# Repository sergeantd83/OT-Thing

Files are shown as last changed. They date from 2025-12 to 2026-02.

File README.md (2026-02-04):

# OTthing
**a compact WiFi <-> OpenTherm (master & slave) interface**

OTthing

## Project homepage
https://www.seegel-systeme.de/2025/01/05/ot-thing-das-universelle-wifi-opentherm-interface/

## discussion
https://community.home-assistant.io/t/ot-thing-an-opentherm-wifi-gateway-with-integrated-ot-master-slave/824667

## Reporting issues
When reporting issues please supply:
* Brand & model of boiler & roomunit
* OTthing firmware version
* status JSON (http://[OTTHING-IP]/status)
* configuration JSON (http://[OTTHING-IP]/config)
* OT status JSON (http://[OTTHING-IP]/otitems)

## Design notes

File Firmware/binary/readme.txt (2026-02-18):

To install binary release:

- Hold down Boot button on OTGW32, plug in to PC, release Boot button
- Double click on flash.bat (Windows) or flash.sh (Linux)
- Press Reset on OTGW32, status LED should flash
- Configure Wi-Fi by connecting to SSID "OT Thing" pw "12345678" then visit http://4.3.2.1/

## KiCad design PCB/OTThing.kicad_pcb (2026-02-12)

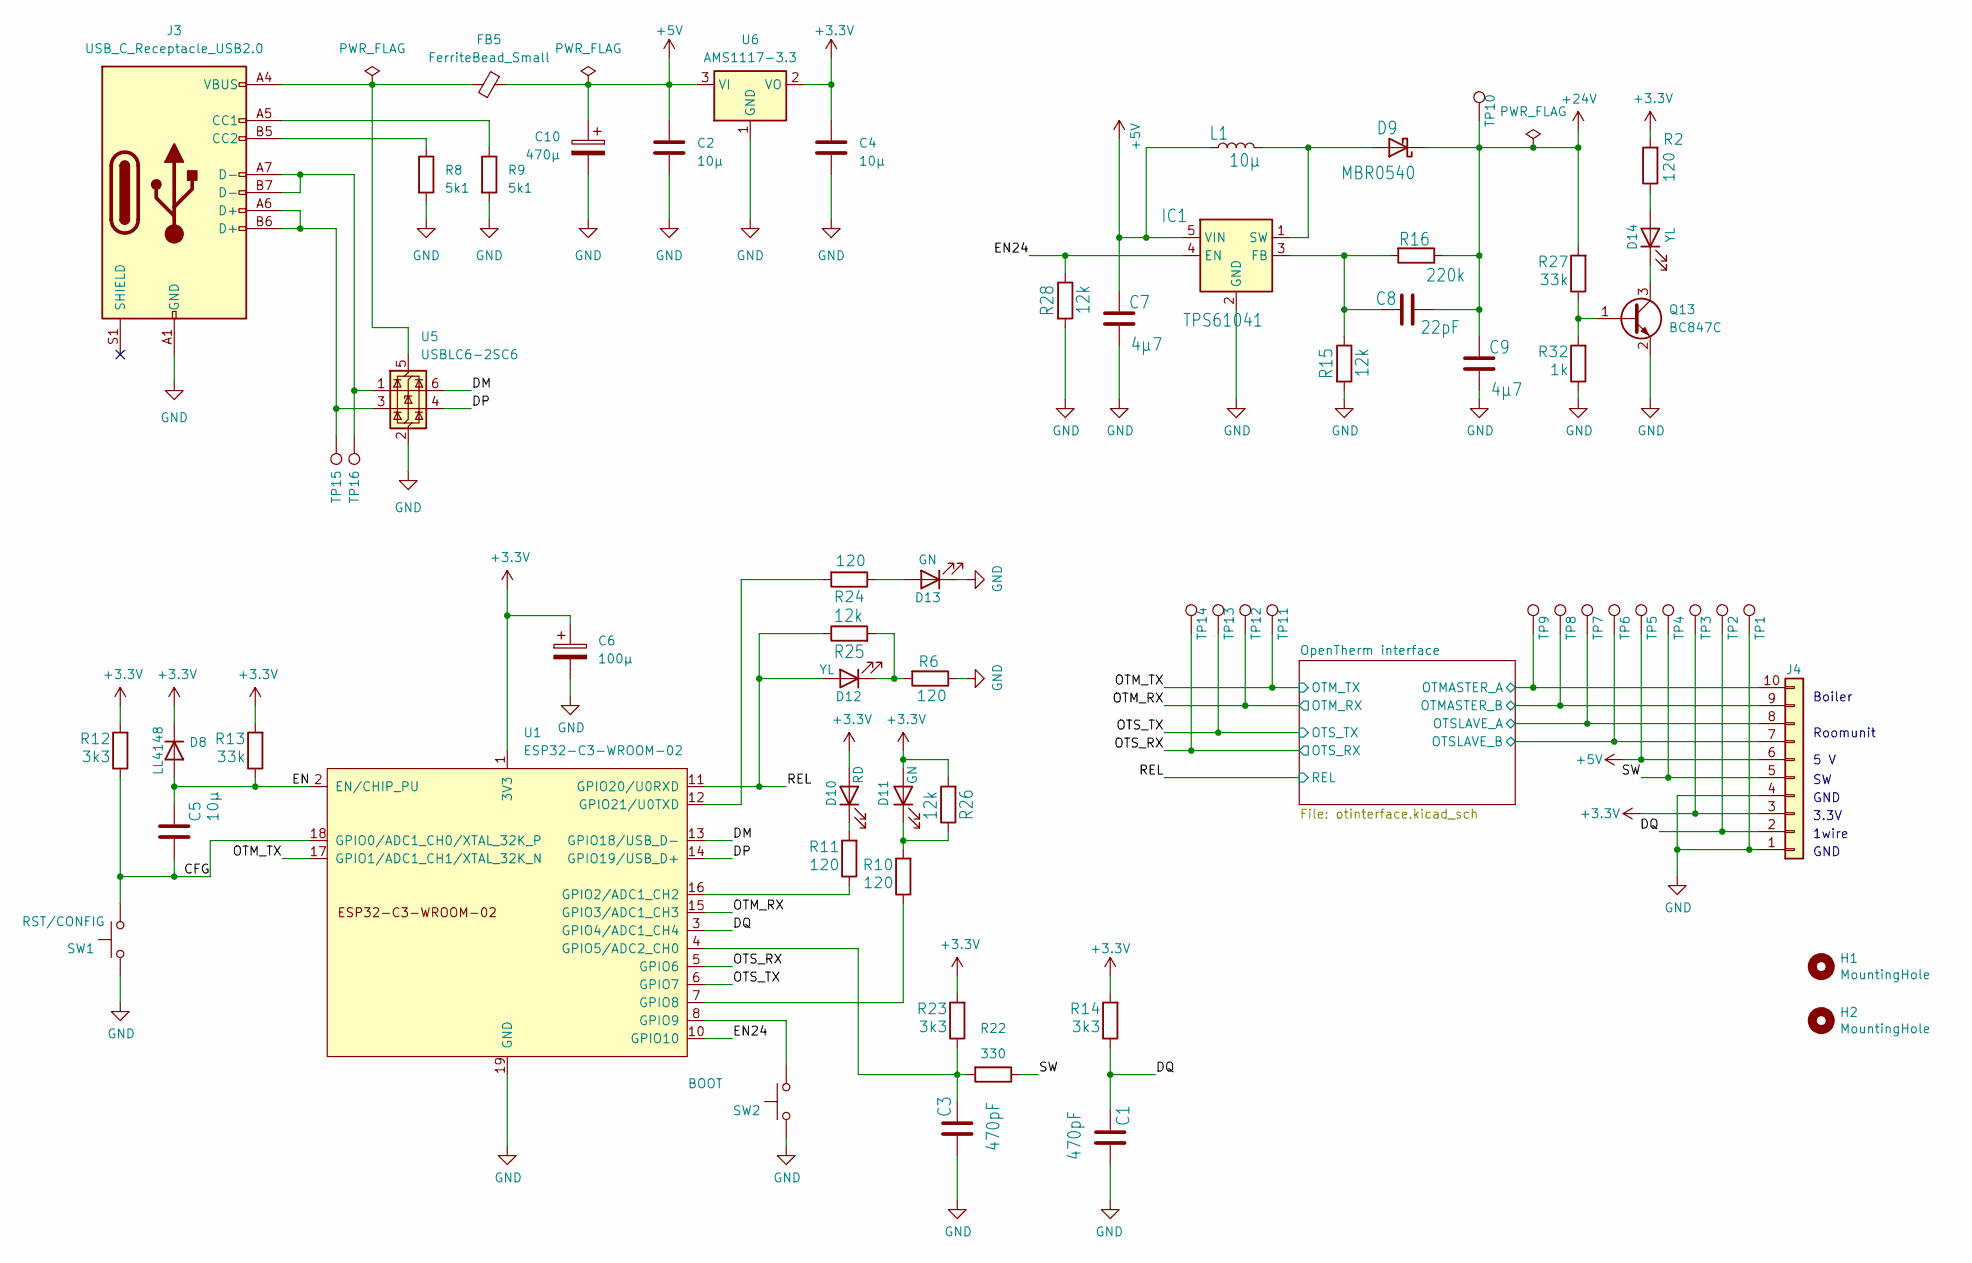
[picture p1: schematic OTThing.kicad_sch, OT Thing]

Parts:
C1, C3: 470pF; C_0805_2012Metric; LCSC C62771
C2, C4, C5: 10µ; C_0805_2012Metric; LCSC C90543
C6: 100µ; CP_Elec_6.3x5.4; LCSC C2887276
C7, C9: 4µ7; C_0805_2012Metric; LCSC C2918489
C8: 22pF; C_0805_2012Metric; LCSC C24658
C10: 470µ; CP_Elec_6.3x7.7; LCSC C87858
D8: LL4148; D_MiniMELF; LCSC C435829
D9: MBR0540; D_SOD-123; LCSC C116159
D10: RD; LED_0805_2012Metric; LCSC C2943978
D11, D13: GN; LED_0805_2012Metric; LCSC C965815
D12, D14: YL; LED_0805_2012Metric; LCSC C965816
FB5: FerriteBead_Small; L_0603_1608Metric; LCSC C1002
H1, H2: MountingHole; MountingHole_2.5mm
IC1: TPS61041; SOT-23-5; LCSC C9846
J3: USB_C_Receptacle_USB2.0; USB_C_Receptacle_HRO_TYPE-C-31-M-12; LCSC C2927038
J4: TerminalBlock_Phoenix_PT-1,5-10-3.5-H_1x10_P3.50mm_Horizont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; LCSC C5184956
L1: 10µ; L_1210_3225Metric; LCSC C98020
Q13: BC847C; SOT-23; LCSC C7420337
R2, R6, R10, R11, R24: 120; R_0805_2012Metric; LCSC C17437
R8, R9: 5k1; R_0805_2012Metric; LCSC C118848
R12, R14, R23: 3k3; R_0805_2012Metric; LCSC C26010
R13, R27: 33k; R_0805_2012Metric; LCSC C17633
R15, R25, R26, R28: 12k; R_0805_2012Metric; LCSC C17444
R16: 220k; R_0805_2012Metric; LCSC C17556
R22: 330; R_0805_2012Metric; LCSC C17630
R32: 1k; R_0805_2012Metric; LCSC C17513
SW1: RST/CONFIG; SW_Tactile_SPST_Angled_PTS645Vx83-2LFS; LCSC C2837540
SW2: BOOT; SW_SPST_CK_RS282G05A3; LCSC C2888954
TP1, TP2, TP3, TP4, TP5, TP6, TP7, TP8, TP9, TP10, TP11, TP12, TP13, TP14, TP15, TP16: TestPoint_THTPad_D1.5mm_Drill0.7mm
U1: ESP32-C3-WROOM-02; LCSC C2934560
U5: USBLC6-2SC6; SOT-23-6; LCSC C2827654
U6: AMS1117-3.3; SOT-223-3_TabPin2; LCSC C347222

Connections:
+3.3V: C4.1, C6.1, D8.1 (K), D10.2 (A), D11.2 (A), J4.3, R2.2, R12.2, R13.2, R14.2, R23.2, R26.2, TP3.1, U1.1 (3V3), U6.2 (VO); also elsewhere on the board
+5V: C2.1, C7.1, C10.1, FB5.2, IC1.5 (VIN), J4.6, L1.1, TP5.1, U6.3 (VI); also elsewhere on the board
+24V: C8.1, C9.1, D9.1 (K), R16.1, R27.2, TP10.1; also elsewhere on the board
/CFG: C5.2, R12.1, SW1.1, U1.18 (GPIO0/ADC1_CH0/XTAL_32K_P)
/DM: U1.13 (GPIO18/USB_D-), U5.6 (I/O1)
/DP: U1.14 (GPIO19/USB_D+), U5.4 (I/O2)
/DQ: C1.1, J4.2, R14.1, TP2.1, U1.3 (GPIO4/ADC1_CH4)
/EN: C5.1, D8.2 (A), R13.1, U1.2 (EN/CHIP_PU)
/EN24: IC1.4 (EN), R28.1, U1.10 (GPIO10)
/OTM_RX: TP12.1, U1.15 (GPIO3/ADC1_CH3); also elsewhere on the board
/OTM_TX: TP11.1, U1.17 (GPIO1/ADC1_CH1/XTAL_32K_N); also elsewhere on the board
/OTS_RX: TP14.1, U1.5 (GPIO6); also elsewhere on the board
/OTS_TX: TP13.1, U1.6 (GPIO7); also elsewhere on the board
/OpenTherm interface/OTMASTER_A: J4.10, TP9.1; also elsewhere on the board
/OpenTherm interface/OTMASTER_B: J4.9, TP8.1; also elsewhere on the board
/OpenTherm interface/OTSLAVE_A: J4.8, TP7.1; also elsewhere on the board
/OpenTherm interface/OTSLAVE_B: J4.7, TP6.1; also elsewhere on the board
/REL: D12.2 (A), R25.1, U1.11 (GPIO20/U0RXD); also elsewhere on the board
/SW: J4.5, R22.1, TP4.1
GND: C1.2, C2.2, C3.2, C4.2, C6.2, C7.2, C9.2, C10.2, D13.1 (K), IC1.2 (GND), J3.A1 (GND), J3.A12 (GND), J3.B1 (GND), J3.B12 (GND), J4.1, J4.4, Q13.2 (E), R6.1, R8.2, R9.2, R15.2, R28.2, R32.1, SW1.2, SW2.2, TP1.1, U1.9 (GND), U1.19 (GND), U5.2 (GND), U6.1 (GND); also elsewhere on the board
unnamed: D9.2 (A), IC1.1 (SW), L1.2
unnamed: D10.1 (K), R11.2
unnamed: D11.1 (K), R10.2, R26.1
unnamed: D12.1 (K), R6.2, R25.2
unnamed: D13.2 (A), R24.1
unnamed: D14.2 (A), R2.1
unnamed: D14.1 (K), Q13.3 (C)
unnamed: C8.2, IC1.3 (FB), R15.1, R16.2
unnamed: J3.A5 (CC1), R9.1
unnamed: J3.B5 (CC2), R8.1
unnamed: J3.A6 (D+), J3.B6 (D+), TP15.1, U5.3 (I/O2)
unnamed: J3.A7 (D-), J3.B7 (D-), TP16.1, U5.1 (I/O1)
unnamed: Q13.1 (B), R27.1, R32.2
unnamed: R11.1, U1.16 (GPIO2/ADC1_CH2)
unnamed: C3.1, R22.2, R23.1, U1.4 (GPIO5/ADC2_CH0)
unnamed: R10.1, U1.7 (GPIO8)
unnamed: SW2.1, U1.8 (GPIO9)
unnamed: R24.2, U1.12 (GPIO21/U0TXD)
unnamed: FB5.1, J3.A4 (VBUS), J3.A9 (VBUS), J3.B4 (VBUS), J3.B9 (VBUS), U5.5 (VBUS)

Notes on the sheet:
Boiler
3.3V
GND
1wire
5 V
Roomunit

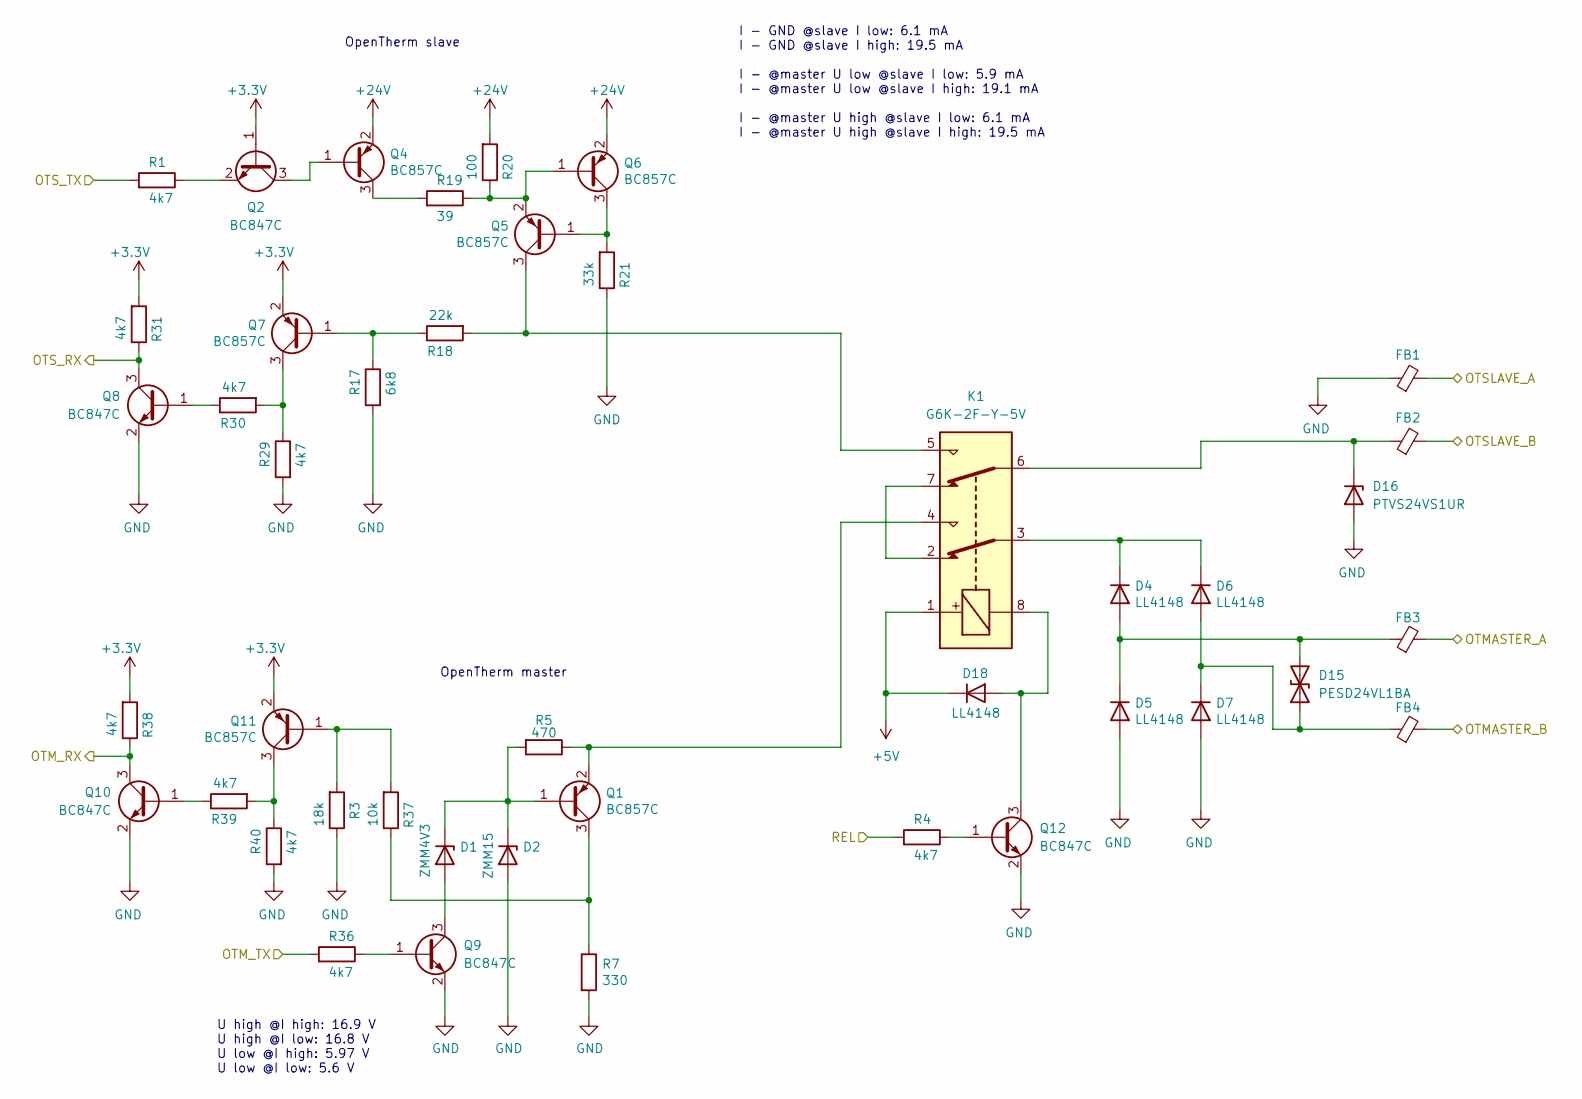
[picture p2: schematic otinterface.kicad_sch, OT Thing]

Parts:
D1: ZMM4V3; D_MiniMELF; LCSC C5345990
D2: ZMM15; D_MiniMELF; LCSC C5346000
D4, D5, D6, D7, D18: LL4148; D_MiniMELF; LCSC C435829
D15: PESD24VL1BA; D_SOD-323; LCSC C2687132
D16: PTVS24VS1UR; D_SOD-123; LCSC C5380693
FB1, FB2, FB3, FB4: L_0603_1608Metric; LCSC C1002
K1: G6K-2F-Y-5V; Relay_DPDT_Omron_G6K-2F-Y; LCSC C2982926
Q1, Q4, Q5, Q6, Q7, Q11: BC857C; SOT-23; LCSC C5204725
Q2, Q8, Q9, Q10, Q12: BC847C; SOT-23; LCSC C7420337
R1, R4, R29, R30, R31, R36, R38, R39, R40: 4k7; R_0805_2012Metric; LCSC C17673
R3: 18k; R_0805_2012Metric; LCSC C17506
R5: 470; R_0805_2012Metric; LCSC C17710
R7: 330; R_0805_2012Metric; LCSC C17630
R17: 6k8; R_0805_2012Metric; LCSC C17772
R18: 22k; R_0805_2012Metric; LCSC C17560
R19: 39; R_0805_2012Metric; LCSC C137534
R20: 100; R_0805_2012Metric; LCSC C17408
R21: 33k; R_0805_2012Metric; LCSC C17633
R37: 10k; R_0805_2012Metric; LCSC C17414

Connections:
+3.3V: Q2.1 (B), Q7.2 (E), Q11.2 (E), R31.2, R38.2; also elsewhere on the board
+5V: D18.1 (K), K1.1; also elsewhere on the board
+24V: Q4.2 (E), Q6.2 (E), R20.2; also elsewhere on the board
/OTM_RX: Q10.3 (C), R38.1; also elsewhere on the board
/OTM_TX: R36.2; also elsewhere on the board
/OTS_RX: Q8.3 (C), R31.1; also elsewhere on the board
/OTS_TX: R1.2; also elsewhere on the board
/OpenTherm interface/OTMASTER_A: FB3.2; also elsewhere on the board
/OpenTherm interface/OTMASTER_B: FB4.2; also elsewhere on the board
/OpenTherm interface/OTSLAVE_A: FB1.2; also elsewhere on the board
/OpenTherm interface/OTSLAVE_B: FB2.2; also elsewhere on the board
/REL: R4.2; also elsewhere on the board
GND: D2.2 (A), D5.2 (A), D7.2 (A), D16.2 (A), FB1.1, Q8.2 (E), Q9.2 (E), Q10.2 (E), Q12.2 (E), R3.1, R7.2, R17.2, R21.1, R29.2, R40.2; also elsewhere on the board
unnamed: D1.2 (A), Q9.3 (C)
unnamed: D1.1 (K), D2.1 (K), Q1.1 (B), R5.2
unnamed: D4.1 (K), D6.1 (K), K1.3
unnamed: D6.2 (A), D7.1 (K), D15.1 (A1), FB4.1
unnamed: D4.2 (A), D5.1 (K), D15.2 (A2), FB3.1
unnamed: D16.1 (K), FB2.1, K1.6
unnamed: D18.2 (A), K1.8, Q12.3 (C)
unnamed: K1.2, K1.7
unnamed: Q1.3 (C), R7.1, R37.1
unnamed: K1.4, Q1.2 (E), R5.1
unnamed: Q2.3 (C), Q4.1 (B)
unnamed: Q2.2 (E), R1.1
unnamed: Q4.3 (C), R19.2
unnamed: Q5.1 (B), Q6.3 (C), R21.2
unnamed: K1.5, Q5.3 (C), R18.2
unnamed: Q5.2 (E), Q6.1 (B), R19.1, R20.1
unnamed: Q7.1 (B), R17.1, R18.1
unnamed: Q7.3 (C), R29.1, R30.2
unnamed: Q8.1 (B), R30.1
unnamed: Q9.1 (B), R36.1
unnamed: Q10.1 (B), R39.1
unnamed: Q11.1 (B), R3.2, R37.2
unnamed: Q11.3 (C), R39.2, R40.1
unnamed: Q12.1 (B), R4.1

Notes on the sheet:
U high @I high: 16.9 V U high @I low: 16.8 V U low @I high: 5.97 V U low @I low: 5.6 V
I - GND @slave I low: 6.1 mA I - GND @slave I high: 19.5 mA I - @master U low @slave I low: 5.9 mA I - @master U low @slave I high: 19.1 mA I - @master U high @slave I low: 6.1 mA I - @master U high @slave I high: 19.5 mA
OpenTherm slave
OpenTherm master

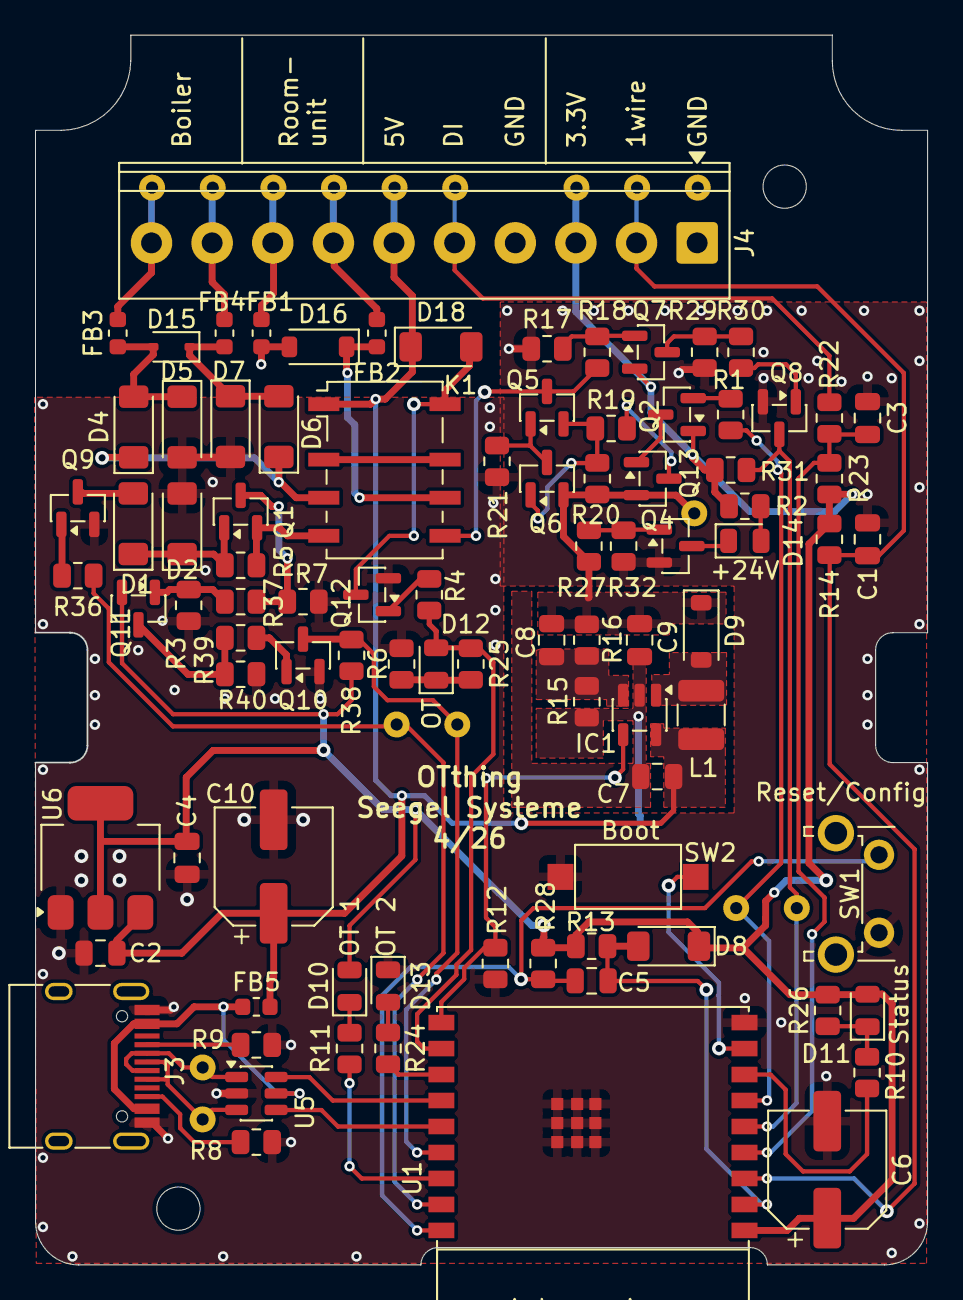
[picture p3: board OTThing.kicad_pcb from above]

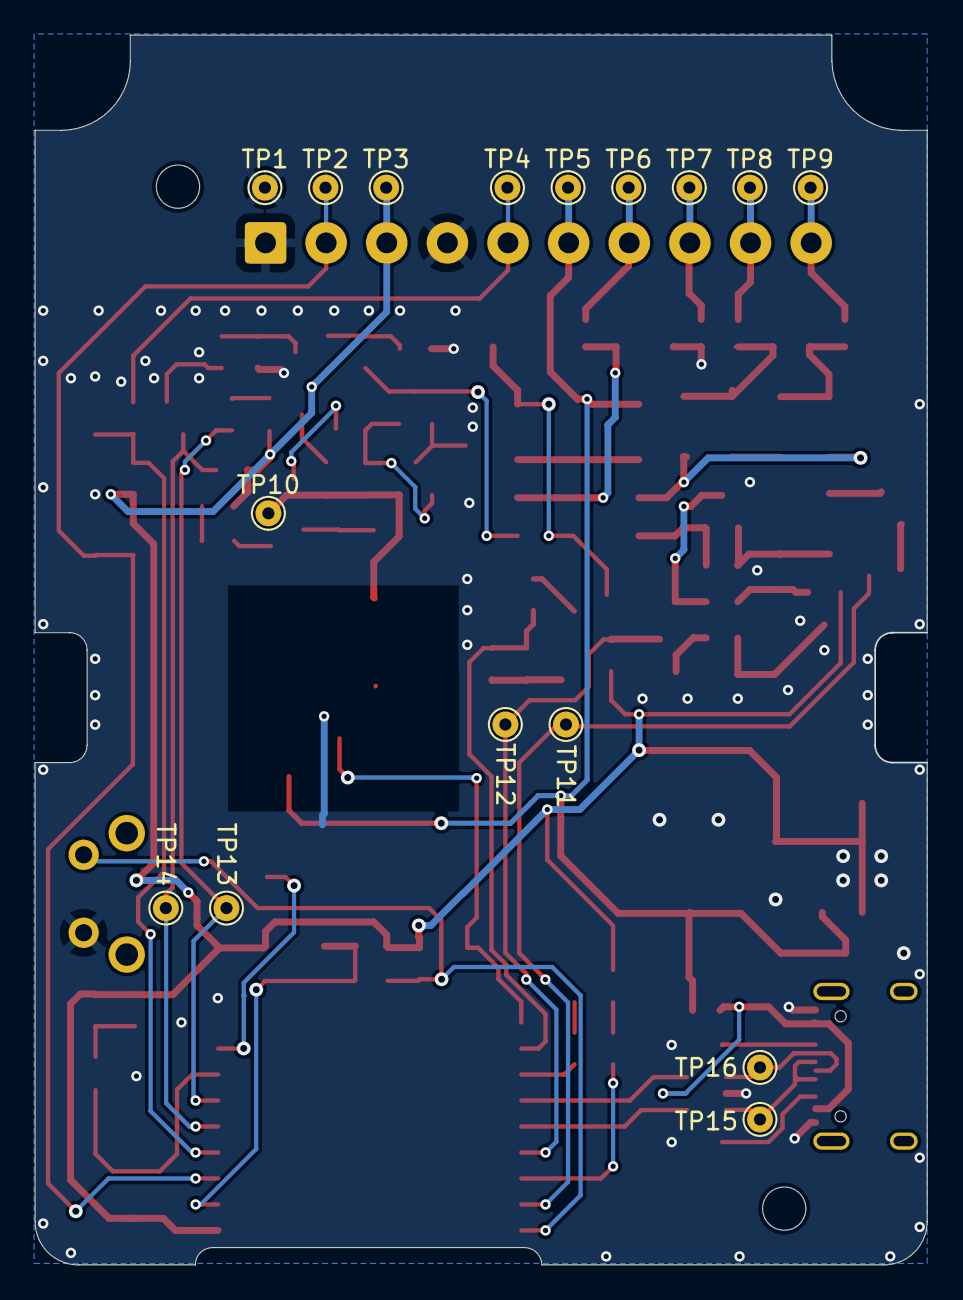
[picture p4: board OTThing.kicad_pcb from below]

Board: 2 copper layers, 51.5 x 71.0 mm, 108 parts (16 on the bottom side), 63 nets.

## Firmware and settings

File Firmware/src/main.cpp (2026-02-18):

#include <Arduino.h>
#include <SPI.h>
#include <WiFi.h>
#include <ESPmDNS.h>
#include <Ticker.h>
#include "hwdef.h"
#include "portal.h"
#include "otcontrol.h"
#include "mqtt.h"
#include "devstatus.h"
#include "devconfig.h"
#include "command.h"
#include "sensors.h"
#include "HADiscLocal.h"
#include <esp_wifi.h>
#include "time.h"
#include "main.h"
#include "esp_task_wdt.h"

#ifdef DEBUG
    #include <ArduinoOTA.h>
#endif

#ifdef NODO
#include <EthernetESP32.h>
SPIClass SPI1(FSPI);
W5500Driver driver(GPIO_SPI_CS, GPIO_SPI_INT, GPIO_SPI_RST);
char buffer[64]; 
byte ethMac[6];
#endif

Ticker statusLedTicker;
volatile uint16_t statusLedData = 0x8000;
bool configMode = false;


// Variables for dynamic network management
unsigned long lastNetworkCheck = 0;
const unsigned long netCheckInterval = 5000; // Check physical link every 5 seconds

void statusLedLoop() {
    static uint16_t mask = 0x8000;

    setLedStatus((statusLedData & mask) != 0);
    mask >>= 1;
    if (!mask)
        mask = 0x8000;
}

void wifiEvent(WiFiEvent_t event) {
#ifdef NODO
    if (configMode) return;
#endif
    switch (event) {
    case ARDUINO_EVENT_WIFI_STA_GOT_IP: {
        String hn = devconfig.getHostname();
        WiFi.setHostname(hn.c_str());
        MDNS.begin(hn.c_str());
        MDNS.addService("http", "tcp", 80);
        break;
    }

    case ARDUINO_EVENT_WIFI_STA_DISCONNECTED:
        // Only trigger reconnect if we aren't currently using Wired Ethernet
        if (!WIRED_ETHERNET_PRESENT) {
            devstatus.numWifiDiscon++;
            WiFi.reconnect();
        }
        break;

    default:
        break;
    }
}



#ifdef NODO
QueueHandle_t button_press_queue;
void IRAM_ATTR nodo_boot_button_interrupt(void *arg) {
  if ( gpio_get_level((gpio_num_t)GPIO_BOOT_BUTTON) == 0 ){
    int64_t t = esp_timer_get_time();
    xQueueSendFromISR(button_press_queue, &t, NULL);
  }
}
const int number_of_pages = 5;
int64_t last_c = 0;
int pageno = 0;

Adafruit_SSD1306 oled_display(SCREEN_WIDTH, SCREEN_HEIGHT, &Wire, -1);

void displayNetworkStatus(unsigned long now) {
  if (!OLED_PRESENT)
      return; // Skip if no display detected

  static unsigned long on_time = 0;
  static int last_pageno_state = 0;

  int64_t c = 0;
  while (xQueueReceive(button_press_queue, &c, 0)) {
    // Debounce check
    if ( (c - last_c ) < 300000 ){
      last_c = c;
      continue;
    }
    last_c = c;
    
    // Cycle pages or turn on if it was off
    if (pageno == 0) {
        pageno = 1;
    } else {
        pageno++;
        if (pageno >= number_of_pages) pageno = 1;
    }
    on_time = now; // Reset timer on manual interaction
  } 

  // --- AUTOMATIC WAKE LOGIC ---
  // If pageno was just set to 1 (by manageNetwork OR button) and it was previously 0
  if (pageno > 0 && last_pageno_state == 0) {
      oled_display.ssd1306_command(SSD1306_DISPLAYON);
      oled_display.setTextSize(1);
      oled_display.setTextColor(SSD1306_WHITE);
      if (on_time == 0) on_time = now; // Only set if not already set by button
  }

  // --- TIMEOUT LOGIC ---
  if ( pageno > 0 && (now - on_time) > 30000 ) {
      oled_display.ssd1306_command(SSD1306_DISPLAYOFF);
      pageno = 0;
      on_time = 0;
  }
  
  last_pageno_state = pageno;

  if (pageno) { // display on, needs updating
    oled_display.clearDisplay();
    oled_display.setCursor(0, 0);
    
    if (pageno==1) {
      if (configMode) { // in config mode
        // Using snprintf to format the string into the buffer
        snprintf(buffer, sizeof(buffer), "SSID: %s", WiFi.softAPSSID().c_str());
        oled_display.println(buffer);
        
        oled_display.setCursor(0, 10);
        snprintf(buffer, sizeof(buffer), "PW: 12345678");
        oled_display.println(buffer);

        oled_display.setCursor(0, 20);
        snprintf(buffer, sizeof(buffer), "http://%s/", WiFi.softAPIP().toString().c_str());
        oled_display.println(buffer);
      } else { // not config mode
        if (WIRED_ETHERNET_PRESENT) { // wired
            oled_display.println(F("Wired Network"));
            
            oled_display.setCursor(0, 10);
            snprintf(buffer, sizeof(buffer), "IP: %s", Ethernet.localIP().toString().c_str());
            oled_display.println(buffer);
        } else { // wifi
          snprintf(buffer, sizeof(buffer), "WiFi: %s", WiFi.SSID().c_str());
          oled_display.println(buffer);

          oled_display.setCursor(0, 10);
          if (WiFi.isConnected()) {
              snprintf(buffer, sizeof(buffer), "IP: %s", WiFi.localIP().toString().c_str());
              oled_display.println(buffer);
          } else {
              oled_display.println(F("Connecting..."));
          }
        }
        oled_display.setCursor(0,30);
        oled_display.println("Press Boot for more");
      } // config mode
    } else if ( pageno > 1 ) { 
      if (millis() > 5000) { 
          devstatus.lock(); 
          JsonDocument doc;
          devstatus.buildDoc(doc);

      if ( pageno == 2 || pageno == 3 ){
        snprintf(buffer, sizeof(buffer), "Heating circuit %d", pageno-1);
        oled_display.println(buffer);
        oled_display.println("");
        JsonArray array = doc["heatercircuit"].as<JsonArray>();
        if ( !array.isNull() && array.size() > (pageno-2) ){
          auto obj = array[pageno-2].as<JsonObject>();
          if ( !obj["roomsetpoint"].isNull() ){
            float rsp = obj["roomsetpoint"];
            snprintf(buffer, sizeof(buffer), "Room setpoint: %.1f", rsp);
            oled_display.println(buffer);
          }
          if ( !obj["roomtemp"].isNull() ){
            float rsp = obj["roomtemp"];
            snprintf(buffer, sizeof(buffer), "Room temp:     %.1f", rsp);
            oled_display.println(buffer);
          }
        } else {
          oled_display.println("Not Found.");
        }
      } else if (pageno == 4 ){
        snprintf(buffer, sizeof(buffer), "Status");
        oled_display.println(buffer);
        oled_display.println("");

        String str = doc["fw_version"];
        snprintf(buffer, sizeof(buffer), "FW version: %s", str.c_str());
        oled_display.println(buffer);
        unsigned ut = doc["runtime"];
        snprintf(buffer, sizeof(buffer), "Runtime:    %u s", ut);
        oled_display.println(buffer);
        if ( !doc["mqtt"].isNull() ){
          snprintf(buffer, sizeof(buffer), "MQTT:       %s", doc["mqtt"]["connected"] == false? "disconnected":"connected");
          oled_display.println(buffer);
          if ( doc["mqtt"]["basetopic"].isNull() ){
            snprintf(buffer, sizeof(buffer), "MQTT topic: n/a");
          } else {
            String str = doc["mqtt"]["basetopic"];
            snprintf(buffer, sizeof(buffer), "MQTT topic: %s", str.c_str());
          }
          oled_display.println(buffer);
        }

      }
      devstatus.unlock();
      } else {
          oled_display.println(F("Loading data..."));
      } 
    }
    // --- Memory Status ---
    // oled_display.setCursor(0, 20);
    // %u is for unsigned int, %lu is for long unsigned (safer for 32-bit heap values)
    // snprintf(buffer, sizeof(buffer), "%lu bytes free", (unsigned long)ESP.getFreeHeap());
    // oled_display.println(buffer);
    
    oled_display.display();
  }
}

// Helper to switch interfaces based on physical link
void manageNetwork() {
    unsigned long now = millis();
    if (now - lastNetworkCheck < netCheckInterval) return;
    lastNetworkCheck = now;

    bool hasLink = (Ethernet.linkStatus() == LinkON);

    // If Ethernet cable just plugged in, but we are currently on WiFi
    if (hasLink && !WIRED_ETHERNET_PRESENT) {
        Serial.println("Ethernet link detected. Switching to Wired...");
        if (!pageno) pageno=1; // wake display
        if (Ethernet.begin(ethMac, 2000)) { 
            WIRED_ETHERNET_PRESENT = true;
            WiFi.disconnect(); // Turn off WiFi to avoid routing conflicts
            Serial.print("Wired IP: ");
            Serial.println(Ethernet.localIP());
            
            String hn = devconfig.getHostname();
            MDNS.begin(hn.c_str());
        }
    } 
    // If Ethernet cable unplugged, but we were using Wired
    else if (!hasLink && WIRED_ETHERNET_PRESENT) {
        if (!pageno) pageno=1; // wake display
        Serial.println("Ethernet link lost. Switching to WiFi...");
        WIRED_ETHERNET_PRESENT = false;
        WiFi.begin(); 
    }
}
#endif // NODO

void setup() {
    Serial.begin();
    Serial.setTxTimeoutMs(100);
    pinMode(GPIO_STATUS_LED, OUTPUT);
    pinMode(GPIO_CONFIG_BUTTON, INPUT);
    
    setLedStatus(false);
#ifdef NODO  // Initialize I2C display and wired ethernet
    const unsigned char flame_bitmap[] PROGMEM = {
        0x01, 0x00, 0x01, 0x00, 0x03, 0x00, 0x03, 0x80, 0x07, 0x80, 0x0f, 0xc0, 0x1f, 0xe0, 0x3f, 0xf0, 
        0x3f, 0xf0, 0x7f, 0xf8, 0x77, 0xf8, 0x73, 0xf8, 0xff, 0xf8, 0xff, 0xf8, 0x3f, 0xf0, 0x1f, 0xe0
    };
    Wire.begin(GPIO_I2C_SDA, GPIO_I2C_SCL);  // SDA=21, SCL=22 (default ESP32 pins)

    // Initialize OLED
    Wire.beginTransmission(0x3C);
    if (Wire.endTransmission() == 0) { // device responded
    if (oled_display.begin(SSD1306_SWITCHCAPVCC, 0x3C)) {
      // Clear buffer
      oled_display.clearDisplay();

      // Set text properties
      oled_display.setTextSize(1);             // Text size multiplier
      oled_display.setTextColor(SSD1306_WHITE);
      oled_display.setCursor(0, 0);          // Position on screen

      // Print message
      oled_display.println("Nodo OTGW32");
      oled_display.setCursor(0, 20);          // Position on screen
      oled_display.println("Press Boot for more");
      oled_display.setCursor(0, 30);          // Position on screen
      oled_display.println("Hold Reset for config");

      // pretty flame
      oled_display.drawBitmap(56, 44, flame_bitmap, 16, 16, WHITE);
      // Push to display
      oled_display.display();
      OLED_PRESENT = true;
      pageno = 1;
    }
  }
  button_press_queue = xQueueCreate(10, sizeof(int64_t));
  gpio_set_direction((gpio_num_t)GPIO_BOOT_BUTTON, GPIO_MODE_INPUT);
  gpio_install_isr_service(ESP_INTR_FLAG_IRAM);
  gpio_set_intr_type((gpio_num_t)GPIO_BOOT_BUTTON, GPIO_INTR_NEGEDGE);
  gpio_intr_enable((gpio_num_t)GPIO_BOOT_BUTTON);
  gpio_isr_handler_add((gpio_num_t)GPIO_BOOT_BUTTON, nodo_boot_button_interrupt,
                       NULL);
  // Initialize Ethernet
  SPI1.begin(GPIO_SPI_SCK, GPIO_SPI_MISO, GPIO_SPI_MOSI);
  driver.setSPI(SPI1);
  driver.setSpiFreq(10);
  driver.setPhyAddress(0);
  Ethernet.init(driver);
  {
    // Get ESP32 MAC
    uint64_t mac64 = ESP.getEfuseMac();
    for (int i = 0; i < 6; i++) {
      ethMac[5 - i] = (mac64 >> (8 * i)) & 0xFF;
    }
    // Mark as locally administered (set bit 1 of first byte)
    ethMac[0] |= 0x02;

    Serial.printf("Derived W5500 MAC: %02X:%02X:%02X:%02X:%02X:%02X\n",
                  ethMac[0], ethMac[1], ethMac[2], ethMac[3], ethMac[4],
                  ethMac[5]);

    // Fast check at boot
    if (Ethernet.begin(ethMac, 1000)) {
      if (Ethernet.linkStatus() == LinkON) {
        WIRED_ETHERNET_PRESENT = true;
      }
    }
  }
#endif
  otcontrol.begin();

  statusLedTicker.attach(0.2, statusLedLoop);

    configMode = digitalRead(GPIO_CONFIG_BUTTON) == 0;
    if (configMode)
        statusLedData = 0xA000;
#ifdef NODO
    if (configMode) {
        WiFi.mode(WIFI_OFF); 
        delay(50);
        WiFi.mode(WIFI_AP); 
    }
#else
    Serial.begin();
    Serial.setTxTimeoutMs(100);
#endif
#ifdef NODO
    if (!configMode) {
#endif
        WiFi.onEvent(wifiEvent);
        WiFi.setSleep(false);
        WiFi.begin();
        AddressableSensor::begin();
        OneWireNode::begin();
        BLESensor::begin();
        haDisc.begin();
        mqtt.begin();
#ifdef NODO
    } 
#endif

    // This is now outside the block, fixing the crash in Config Mode
    devconfig.begin(); 
    configTime(devconfig.getTimezone(), 3600, PSTR("pool.ntp.org"));
#ifdef NODO
    devstatus.lock();
    delay(50); // Hold it long enough for the RTOS to register the allocation
    devstatus.unlock();
#endif
    portal.begin(configMode);

#ifdef NODO
    delay(500);
    if (!configMode)
#endif
        command.begin();
#ifdef NODO
    if (!configMode) { // Only enable the watchdog in Normal Mode
#endif
        esp_task_wdt_config_t wdt_config = {
#ifdef NODO
            .timeout_ms = 10000,
            .idle_core_mask = (1 << 0) | (1 << 1), // check both cores
#else
            .timeout_ms = 6000,
            .idle_core_mask = (1 << 0), // check both cores
#endif
            .trigger_panic = true
        };
        esp_task_wdt_init(&wdt_config);
        esp_task_wdt_add(NULL);
#ifdef NODO
    }
#endif
#ifdef DEBUG
    ArduinoOTA.begin();
#endif
}

void loop() {
    unsigned long now = millis();
#ifdef NODO
    yield(); // keep WDT happy
    if (!configMode) {
#endif
    static unsigned long btnDown = 0;
    if (digitalRead(GPIO_CONFIG_BUTTON) == 0) {
        if ((now - btnDown) > 10000) {
            statusLedTicker.detach();
            setLedStatus(true);
            devconfig.remove();
            WiFi.persistent(true);
            WiFi.disconnect(true, true);
            while (digitalRead(GPIO_CONFIG_BUTTON) == 0) {
                esp_task_wdt_reset();
                yield();
            }
            ESP.restart();
        }
        esp_task_wdt_reset();
    }
    else
        btnDown = now;
#ifdef NODO
    }
#endif 

#ifdef DEBUG
    ArduinoOTA.handle();
#endif
    
#ifdef NODO
    // Check for physical link status and swap if needed
    if (!configMode) 
        manageNetwork();
    else
        delay(1); // keep WDT happy

    static unsigned long lastDisplayUpdate = 0;
    if (now - lastDisplayUpdate > 1000 || uxQueueMessagesWaiting(button_press_queue)) { 
        displayNetworkStatus(now); 
        lastDisplayUpdate = now;
    }

    if (WIRED_ETHERNET_PRESENT) 
        Ethernet.maintain(); /* keep DHCP lease etc */
#endif 

    esp_task_wdt_reset();
    portal.loop();
    mqtt.loop();
    otcontrol.loop();
    Sensor::loopAll();
    devconfig.loop();
    OneWireNode::loop();
}

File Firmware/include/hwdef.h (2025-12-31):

#pragma once
#ifdef NODO
/* probably should be here for all versions */
#include <WiFi.h>
// for OLED display
#include <Wire.h>
#include <Adafruit_GFX.h>
#include <Adafruit_SSD1306.h>
// for W5500 wi-fi
#include <SPI.h>
#include <Ethernet.h>
extern bool WIRED_ETHERNET_PRESENT; 
/* pin defs for Nodo OTGW32 PCB */
#define GPIO_BOOT_BUTTON 0
#define GPIO_CONFIG_BUTTON 9
#define GPIO_STATUS_LED 8
#define GPIO_OTRED_LED 2
#define GPIO_OTGREEN_LED 48
#define GPIO_BYPASS_RELAY 47 /* not connected on Nodo but need for compilation */
#define GPIO_STEPUP_ENABLE 10
#define GPIO_1WIRE_DIO 4
#define GPIO_OTSLAVE_IN 6
#define GPIO_OTSLAVE_OUT 7
#define GPIO_OTMASTER_IN 21
#define GPIO_OTMASTER_OUT 1
/* for I2C OLED display */
#define GPIO_I2C_SCL 17
#define GPIO_I2C_SDA 18
#define GPIO_SPI_CS 14
/* for SPI W5500 Ethernet */
#define GPIO_SPI_MISO 13
#define GPIO_SPI_MOSI 11
#define GPIO_SPI_SCK 12
#define GPIO_SPI_INT 15
#define GPIO_SPI_RST 16
// OLED display width and height
#define SCREEN_WIDTH 128
#define SCREEN_HEIGHT 64
#define LED_BRIGHTNESS 5 // 0-255 
#else
#define GPIO_CONFIG_BUTTON 0
#define GPIO_STATUS_LED 8
#define GPIO_OTRED_LED 2
#define GPIO_OTGREEN_LED 21
#define GPIO_BYPASS_RELAY 20
#define GPIO_STEPUP_ENABLE 10
#define GPIO_1WIRE_DIO 4
#define GPIO_OTSLAVE_IN 6
#define GPIO_OTSLAVE_OUT 7
#define GPIO_OTMASTER_IN 3
#define GPIO_OTMASTER_OUT 1
#endif

inline void setLedOTRed(const bool on) {
#ifdef NODO
    static int init = 0;
    if ( !init ) {
      ledcAttachChannel(GPIO_OTRED_LED, 5000, 8, 2); 
      ledcOutputInvert(GPIO_OTRED_LED, true);
      init = 1;
    }
    if (!on) {
      ledcWrite(GPIO_OTRED_LED, 0);
    } else {
      ledcWrite(GPIO_OTRED_LED, LED_BRIGHTNESS); // dim
    }
#else
    digitalWrite(GPIO_OTRED_LED, !on);
#endif
}

inline void setLedOTGreen(const bool on) {
#ifdef NODO
    static int init = 0;
    if ( !init ) {
      ledcAttachChannel(GPIO_OTGREEN_LED, 5000, 8, 1); 
      ledcOutputInvert(GPIO_OTGREEN_LED, false);
      init = 1;
    }
    if (!on) {
      ledcWrite(GPIO_OTGREEN_LED, 0);
    } else {
      ledcWrite(GPIO_OTGREEN_LED, LED_BRIGHTNESS); // dim
    }
#else
    digitalWrite(GPIO_OTGREEN_LED, !on);
#endif
}

inline void setLedStatus(const bool on) {
#ifdef NODO
    static int init = 0;
    if ( !init ) {
      ledcAttachChannel(GPIO_STATUS_LED, 5000, 8, 0); 
      ledcOutputInvert(GPIO_STATUS_LED, true);
      init = 1;
    }
    if (!on) {
      ledcWrite(GPIO_STATUS_LED, 0); // dim
    } else {
      ledcWrite(GPIO_STATUS_LED, LED_BRIGHTNESS); // dim
    }
#else
    digitalWrite(GPIO_STATUS_LED, !on);
#endif
}

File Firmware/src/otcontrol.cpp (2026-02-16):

#include <WiFi.h>
#include "otcontrol.h"
#include "otvalues.h"
#include "command.h"
#include "HADiscLocal.h"
#include "mqtt.h"
#include "hwdef.h"
#include "portal.h"
#include "sensors.h"

const int PI_INTERVAL = 60; // seconds
const char SLAVE_BRAND[] PROGMEM = "Seegel Systeme";

OTControl otcontrol;

constexpr uint16_t floatToOT(double f) {
    return (((int) f) << 8) | (int) ((f - (int) f) * 256);
}

constexpr uint16_t nib(uint8_t hb, uint8_t lb) {
    return (hb << 8) | lb;
}

// Testdata for local OT slave, can be read by a connected master
const struct {
    OpenThermMessageID id;
    uint16_t value;
} loopbackTestData[] PROGMEM = {
    {OpenThermMessageID::SConfigSMemberIDcode,      nib(1<<0 | 1<<5, 1)}, // DHW & CH2 present, Member ID 1
    {OpenThermMessageID::ASFflags,                  0x0000}, // no error flags, oem error code 0
    {OpenThermMessageID::RBPflags,                  0x0101},
    {OpenThermMessageID::TrOverride,                0},
    {OpenThermMessageID::MaxCapacityMinModLevel,    nib(20, 5)}, // 20 kW / 5 %
    {OpenThermMessageID::RelModLevel,               floatToOT(33.3)},
    {OpenThermMessageID::CHPressure,                floatToOT(1.25)},
    {OpenThermMessageID::DHWFlowRate,               floatToOT(2.4)},
    {OpenThermMessageID::Tboiler,                   floatToOT(48.5)},
    {OpenThermMessageID::Tdhw,                      floatToOT(37.5)},
    {OpenThermMessageID::Toutside,                  floatToOT(3.5)},
    {OpenThermMessageID::Tret,                      floatToOT(41.7)},
    {OpenThermMessageID::TflowCH2,                  floatToOT(48.6)},
    {OpenThermMessageID::Tdhw2,                     floatToOT(37.6)},
    {OpenThermMessageID::Texhaust,                  90},
    {OpenThermMessageID::TrOverride2,               0},
    {OpenThermMessageID::TdhwSetUBTdhwSetLB,        nib(60, 40)}, // 60 °C upper bound, 40 C° lower bound
    {OpenThermMessageID::MaxTSetUBMaxTSetLB,        nib(60, 25)}, // 60 °C upper bound, 20 C° lower bound
    {OpenThermMessageID::PowerCycles,               159},
    {OpenThermMessageID::SuccessfulBurnerStarts,    9999},
    {OpenThermMessageID::CHPumpStarts,              7777},
    {OpenThermMessageID::DHWPumpValveStarts,        5544},
    {OpenThermMessageID::DHWBurnerStarts,           9955},
    {OpenThermMessageID::BurnerOperationHours,      8888},
    {OpenThermMessageID::CHPumpOperationHours,      6666},
    {OpenThermMessageID::DHWPumpValveOperationHours,5555},
    {OpenThermMessageID::DHWBurnerOperationHours,   2222},
    {OpenThermMessageID::OpenThermVersionSlave,     nib(2, 2)},
    {OpenThermMessageID::SlaveVersion,              nib(4, 4)},
    {OpenThermMessageID::StatusVentilationHeatRecovery, 0x001E},
    {OpenThermMessageID::RelVentLevel,              55}, // relative ventilation 0..100 %
    {OpenThermMessageID::RHexhaust,                 45},
    {OpenThermMessageID::CO2exhaust,                1450}, // PPM
    {OpenThermMessageID::Tsi,                       floatToOT(22.1)},
    {OpenThermMessageID::Tso,                       floatToOT(22.2)},
    {OpenThermMessageID::Tei,                       floatToOT(22.3)},
    {OpenThermMessageID::Teo,                       floatToOT(22.1)},
    {OpenThermMessageID::RPMexhaust,                2300},
    {OpenThermMessageID::RPMsupply,                 2400},
    {OpenThermMessageID::ASFflagsOEMfaultCodeVentilationHeatRecovery,   0x0F33},
    {OpenThermMessageID::OpenThermVersionVentilationHeatRecovery,       0x0105},
    {OpenThermMessageID::VentilationHeatRecoveryVersion,                0x0107},
    {OpenThermMessageID::RemoteOverrideFunction,    0x0000},
    {OpenThermMessageID::UnsuccessfulBurnerStarts,  19},
    {OpenThermMessageID::FlameSignalTooLowNumber,   4},
    {OpenThermMessageID::OEMDiagnosticCode,         123},
    {OpenThermMessageID::TboilerHeatExchanger,      floatToOT(48.5)},
    {OpenThermMessageID::BoilerFanSpeedSetpointAndActual, nib(20, 21)},
    {OpenThermMessageID::FlameCurrent,              floatToOT(96.8)},
};


void clip(double &d, const double min, const double max) {
    if (d < min)
        d = min;
    if (d > max)
        d = max;
}

class SemMaster {
private:
    BaseType_t result;
public:
    SemMaster(const uint16_t timeout) {
        result = xSemaphoreTakeRecursive(otcontrol.master.mutex, (TickType_t) timeout / portTICK_PERIOD_MS);
        wait();
    }

    ~SemMaster() {
        if (result == true) {
            wait();
            xSemaphoreGiveRecursive(otcontrol.master.mutex);
        }
    }

    operator bool() {
        return (result == pdTRUE) && otcontrol.master.hal.isReady();
    }

    void wait() {
        if (result == pdTRUE) {
            TickType_t start = xTaskGetTickCount();

            while (!otcontrol.master.hal.isReady()) {
#ifdef NODO // try to prevent watchdog reset
                yield(); // allow other tasks to run
#endif
                if ((xTaskGetTickCount() - start) > pdMS_TO_TICKS(2000))
                    break;

                otcontrol.hwYield();
            }
        }
    }
};

void IRAM_ATTR handleIrqMaster() {
    otcontrol.masterPinIrq();
}

void IRAM_ATTR handleIrqSlave() {
    otcontrol.slavePinIrq();
}

//OpenTherm master callback
void otCbMaster(unsigned long response, OpenThermResponseStatus status) {
    otcontrol.OnRxMaster(response, status);
}

//OpenTherm slave callback
void otCbSlave(unsigned long response, OpenThermResponseStatus status) {
    otcontrol.OnRxSlave(response, status);
}

OTControl::OTInterface::OTInterface(const uint8_t inPin, const uint8_t outPin, const bool isSlave):
        hal(inPin, outPin, isSlave) {
    resetCounters();
    mutex = xSemaphoreCreateRecursiveMutex();
}

void OTControl::OTInterface::sendRequest(const char source, const unsigned long msg) {
    hal.sendRequestAsync(msg);
    
    if (source)
        command.sendOtEvent(source, msg);
    
    txCount++;
    lastTx = millis();
    lastTxMsg = msg;
}

void OTControl::OTInterface::resetCounters() {
    txCount = 0;
    rxCount = 0;
    timeoutCount = 0;
    invalidCount = 0;
}

void OTControl::OTInterface::onReceive(const char source, const unsigned long msg) {
    if (source)
        command.sendOtEvent(source, msg);
    rxCount++;
    lastRx = millis();
}

void OTControl::OTInterface::sendResponse(const unsigned long msg, const char source) {
    uint32_t temp = millis();

    while (true) {
        if (hal.sendResponse(msg)) {
            if (source)
                command.sendOtEvent(source, msg);
        
            txCount++;
            lastTx = millis();
            lastTxMsg = msg;
            break;
        }
        if (millis() - temp > 300)
            break;

        hal.process();
        yield();
    }
}
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

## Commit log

2025-12-23 Robert's fix for noStoredWifi
    [main.cpp]
2025-12-24 [Ethernet] Fix logic to be correct.
    [main.cpp]
2025-12-27 Implement high power mode
2025-12-27 Make gateway always say it can supply high power even if boiler cannot
2025-12-28 make MQTT work on wired
2025-12-29 10 second timer
2025-12-31 [LEDS] Make code more unify, use LedOutputInvert for inverted leds.
    [hwdef.h]
2026-01-01 Dynamic network switching
2026-02-04 ArduinoJson.h != ArduinoJSON.h
2026-02-18 BLE sensors report 2 decimals instead of 1.
